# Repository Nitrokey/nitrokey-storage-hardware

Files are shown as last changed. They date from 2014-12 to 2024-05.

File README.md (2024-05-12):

# Nitrokey Storage 2

This repository contains the hardware layout and schematics of the Nitrokey Storage and Nitrokey Storage 2.

## Replacing PCB

You can replace your Nitrokey Storage hardware (PCB) within a few minutes by following these steps:

1. Backup all your data from the Nitrokey. Understand that the RSA keys will be replaced and all data be destroyed!

2. Remove the lid from the USB socket of the Nitrokey.

3. Use a knife to open the casing until you have the PCB removed completely.

4. Remove the smart card and the MicroSD card from the PCB and push them in the new replacement PCB.

5. Place the PCB in the new bottom casing, the one with the CE and FC engravings.

6. Add the other casing (with the Nitrokey label) on top of the bottom casing. Press both casings carefully together until it clicks and the gap is completely closed.

7. Connect the Nitrokey to your computer. Start the Nitrokey App and select “Destroy Encrypted Data” from “Configuration” sub-menu. Note that this will destroy all existing RSA keys and encrypted data.

Your Nitrokey is now ready to use. In case of any problems, please send us an email.

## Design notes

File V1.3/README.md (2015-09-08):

Nitrokey Storage hardware
=========================

Hi hardware freaks,
to use this layout you need the designtool [Designspark PCB](http://www.designspark.com/) (free)

Install the software, the open the projectfile

for the **PROD** version

stick20-p.prj

for the **DEVELOPER** version

Stick20.prj

This work is licensed under the Creative Commons Attribution-ShareAlike 3.0 Unported License. 
To view a copy of this license, visit http://creativecommons.org/licenses/by-sa/3.0/ or send 
a letter to Creative Commons, 444 Castro Street, Suite 900, Mountain View, California, 94041, USA.

Feel free to work with it.

Rudi

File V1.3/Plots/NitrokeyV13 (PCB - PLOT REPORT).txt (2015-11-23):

PLOT REPORT
-----------

Report File:        E:\rudi\Stick\Repositorys\Nitrokey_Hardware\nitrokey-storage-hardware\V1.3\NitrokeyV13 (PCB - PLOT REPORT).txt
Report Written:     Friday, November 20, 2015
Project Path:       E:\rudi\Stick\Repositorys\Nitrokey_Hardware\nitrokey-storage-hardware\V1.3\NitrokeyV13.prj
Design Path:        E:\rudi\Stick\Repositorys\Nitrokey_Hardware\nitrokey-storage-hardware\V1.3\NitrokeyV13.pcb
Design Title:       
Created:            09.09.2011 16:00:27
Last Saved:         20.11.2015 13:58:34
Editing Time:       18637 min
Units:              mm (precision 4)

Device Settings
===============

Gerber Settings
===============

    Leading zero suppression.
    G01 assumed throughout.
    Line termination <*> <CR> <LF>.
    2.5 format absolute inches.

    Format commands defined in Gerber file.
    Aperture table defined in Gerber file.
    Hardware arcs allowed.

Drill Settings
==============

    Excellon Format 1    Format 3.5 absolute in mm.
    No zero suppression.

Plots Output
============

    Plot Job: "E:\rudi\Stick\Repositorys\Nitrokey_Hardware\nitrokey-storage-hardware\V1.3\NitrokeyV13.mop"

Gerber Output
=============

E:\rudi\Stick\Repositorys\Nitrokey_Hardware\nitrokey-storage-hardware\V1.3\Plots\NitrokeyV13 - Top Silkscreen.gbr

    Layers:
    ------------------
    Top Silkscreen
    Board Outlines

    D-Code Shape  (thou)
    -----------------------
    D10    Round 5.00
    D11    Round 4.00
    D12    Round 3.15
    D13    Round 1.97
    D14    Round 8.00
    D15    Round 1.00

Gerber Output
=============

E:\rudi\Stick\Repositorys\Nitrokey_Hardware\nitrokey-storage-hardware\V1.3\Plots\NitrokeyV13 - Top Copper.gbr

    Layers:
    ------------------
    Top Copper
    Board Outlines

    D-Code Shape  (thou)
    ----------------------------------------------
    D10    Round 5.00
    D16    Rectangle 43.31 X 39.37
    D17    Rectangle 51.18 X 59.06
    D18    Rectangle 41.34 X 42.52  Rotation 90
    D19    Rectangle 41.34 X 42.52
    D70    Rectangle 43.31 X 39.37  Rotation 90
    D71    Round 13.78
    D20    Rectangle 48.00 X 88.00
    D21    Rectangle 141.73 X 86.61
    D22    Rectangle 39.37 X 43.31
    D23    Rectangle 39.37 X 43.31  Rotation 90
    D24    Rectangle 86.61 X 47.24
    D25    Round 130.55
    D26    Round 59.18
    D27    Rectangle 59.06 X 74.80
    D28    Rectangle 55.12 X 70.87  Rotation 90
    D29    Round 39.37
    D72    Rectangle 23.62 X 47.24
    D73    Round 17.72
    D74    Round 24.00
    D75    Round 16.00
    D76    Round 12.00
    D77    Round 5.90
    D78    Round 47.24
    D79    Round 37.40

Gerber Output
=============

E:\rudi\Stick\Repositorys\Nitrokey_Hardware\nitrokey-storage-hardware\V1.3\Plots\NitrokeyV13 - Top Copper (Paste).gbr

    Layers:
    ------------------
    Top Copper
    Board Outlines

    D-Code Shape  (thou)
    ----------------------------------------------
    D10    Round 5.00
    D80    Rectangle 39.31 X 35.37
    D81    Rectangle 47.18 X 55.06
    D82    Rectangle 37.34 X 38.52  Rotation 90
    D83    Rectangle 37.34 X 38.52
    D84    Rectangle 39.31 X 35.37  Rotation 90
    D85    Round 9.78
    D86    Rectangle 44.00 X 84.00
    D87    Rectangle 137.73 X 82.61
    D88    Rectangle 35.37 X 39.31
    D89    Rectangle 35.37 X 39.31  Rotation 90
    D90    Rectangle 82.61 X 43.24
    D91    Rectangle 55.06 X 70.80
    D92    Rectangle 51.12 X 66.87  Rotation 90
    D93    Round 35.37
    D94    Rectangle 19.62 X 43.24

Gerber Output
=============

E:\rudi\Stick\Repositorys\Nitrokey_Hardware\nitrokey-storage-hardware\V1.3\Plots\NitrokeyV13 - Documentation.gbr

    Layers:
    ------------------
    Documentation
    Board Outlines

    D-Code Shape  (thou)
    -----------------------
    D10    Round 5.00
    D11    Round 4.00
    D15    Round 1.00
    D95    Round 6.00

Gerber Output
=============

E:\rudi\Stick\Repositorys\Nitrokey_Hardware\nitrokey-storage-hardware\V1.3\Plots\NitrokeyV13 - Top Solder Mask.gbr

    Layers:
    -------------------
    Top Solder Mask
    Board Outlines

    D-Code Shape  (thou)
    ----------------------------------------------
    D10    Round 5.00
    D96    Rectangle 49.31 X 45.37
    D97    Rectangle 57.18 X 65.06
    D98    Rectangle 47.34 X 48.52  Rotation 90
    D99    Rectangle 47.34 X 48.52
    D100   Rectangle 49.31 X 45.37  Rotation 90
    D101   Round 19.78
    D102   Rectangle 54.00 X 94.00
    D103   Rectangle 147.73 X 92.61
    D104   Rectangle 45.37 X 49.31
    D105   Rectangle 45.37 X 49.31  Rotation 90
    D106   Rectangle 92.61 X 53.24
    D107   Round 136.55
    D108   Round 65.18
    D109   Rectangle 65.06 X 80.80
    D110   Rectangle 61.12 X 76.87  Rotation 90
    D111   Round 45.37
    D112   Rectangle 29.62 X 53.24

Gerber Output
=============

E:\rudi\Stick\Repositorys\Nitrokey_Hardware\nitrokey-storage-hardware\V1.3\Plots\NitrokeyV13 - VDD Plane (Powerplane).gbr

    Layers:
    ----------------------------------------------------------------------------------------
    VDD Plane       - Plane Isolation Gap 15.75 Thermal Connect Width 10.00 with 4 Spokes
    Board Outlines

    D-Code Shape  (thou)
    -----------------------------------------
    D113   Round 162.05
    D114   Round 90.68
    D115   Round 17.72  Thermal Relief Pad
    D116   Round 24.00  Thermal Relief Pad
    D117   Round 16.00  Thermal Relief Pad
    D118   Round 55.50
    D119   Round 49.21
    D120   Round 47.50
    D121   Round 70.87
    D122   Round 68.90
    D123   Round 36.50

Gerber Output
=============

E:\rudi\Stick\Repositorys\Nitrokey_Hardware\nitrokey-storage-hardware\V1.3\Plots\NitrokeyV13 - GND Plane (Powerplane).gbr

    Layers:
    ----------------------------------------------------------------------------------------
    GND Plane       - Plane Isolation Gap 15.75 Thermal Connect Width 10.00 with 4 Spokes
    Board Outlines

    D-Code Shape  (thou)
    ------------------------------------------
    D114   Round 90.68
    D115   Round 17.72  Thermal Relief Pad
    D116   Round 24.00  Thermal Relief Pad
    D117   Round 16.00  Thermal Relief Pad
    D118   Round 55.50
    D119   Round 49.21
    D120   Round 47.50
    D121   Round 70.87
    D122   Round 68.90
    D123   Round 36.50
    D124   Round 130.55  Thermal Relief Pad

Gerber Output
=============

E:\rudi\Stick\Repositorys\Nitrokey_Hardware\nitrokey-storage-hardware\V1.3\Plots\NitrokeyV13 - Bottom Copper.gbr

    Layers:
    ------------------
    Bottom Copper
    Board Outlines

    D-Code Shape  (thou)
    ----------------------------------------------
    D10    Round 5.00
    D25    Round 130.55
    D26    Round 59.18
    D29    Round 39.37
    D73    Round 17.72
    D74    Round 24.00
    D75    Round 16.00
    D76    Round 12.00
    D77    Round 5.90
    D79    Round 37.40
    D125   Round 3.94
    D126   Rectangle 39.37 X 66.93  Rotation 90
    D127   Rectangle 33.46 X 62.99
    D128   Rectangle 65.75 X 70.87
    D129   Rectangle 53.15 X 80.71  Rotation 90
    D130   Rectangle 29.53 X 62.99
    D131   Rectangle 72.83 X 74.80  Rotation 90
    D132   Rectangle 25.59 X 84.65
    D133   Rectangle 47.24 X 51.18
    D134   Rectangle 66.93 X 94.49  Rotation 90
    D135   Rectangle 21.26 X 31.50

Gerber Output
=============

E:\rudi\Stick\Repositorys\Nitrokey_Hardware\nitrokey-storage-hardware\V1.3\Plots\NitrokeyV13 - Bottom Copper (Paste).gbr

    Layers:
    ------------------
    Bottom Copper
    Board Outlines

    D-Code Shape  (thou)
    ----------------------------------------------
    D10    Round 5.00
    D93    Round 35.37
    D136   Rectangle 35.37 X 62.93  Rotation 90
    D137   Rectangle 29.46 X 58.99
    D138   Rectangle 61.75 X 66.87
    D139   Rectangle 49.15 X 76.71  Rotation 90
    D140   Rectangle 25.53 X 58.99
    D141   Rectangle 68.83 X 70.80  Rotation 90
    D142   Rectangle 21.59 X 80.65
    D143   Rectangle 43.24 X 47.18
    D144   Rectangle 62.93 X 90.49  Rotation 90
    D145   Rectangle 17.26 X 27.50

Gerber Output
=============

E:\rudi\Stick\Repositorys\Nitrokey_Hardware\nitrokey-storage-hardware\V1.3\Plots\NitrokeyV13 - Bottom Silkscreen.gbr

    Layers:
    ---------------------
    Bottom Silkscreen

    D-Code Shape  (thou)
    -----------------------
    D10    Round 5.00
    D13    Round 1.97
    D14    Round 8.00

Gerber Output
=============

E:\rudi\Stick\Repositorys\Nitrokey_Hardware\nitrokey-storage-hardware\V1.3\Plots\NitrokeyV13 - Bottom Solder Mask.gbr

    Layers:
    ----------------------
    Bottom Solder Mask
    Board Outlines

    D-Code Shape  (thou)
    -----------------------------------------------
    D10    Round 5.00
    D107   Round 136.55
    D108   Round 65.18
    D111   Round 45.37
    D146   Rectangle 45.37 X 72.93  Rotation 90
    D147   Rectangle 39.46 X 68.99
    D148   Rectangle 71.75 X 76.87
    D149   Rectangle 59.15 X 86.71  Rotation 90
    D150   Rectangle 35.53 X 68.99
    D151   Rectangle 78.83 X 80.80  Rotation 90
    D152   Rectangle 31.59 X 90.65
    D153   Rectangle 53.24 X 57.18
    D154   Rectangle 72.93 X 100.49  Rotation 90
    D155   Rectangle 27.26 X 37.50

NC Drill Output
===============

E:\rudi\Stick\Repositorys\Nitrokey_Hardware\nitrokey-storage-hardware\V1.3\Plots\NitrokeyV13 - Drill Data - [Through Hole].drl

    Output:
    ---------------------------
    Plated Round Drill Holes
    Plated Slots
    Plated Board Outlines

    Tool  Size         Count   ID
    ------------------------------------
    T001  000.00787 in 27    I
    T002  000.00800 in 12    D
    T003  000.01200 in 51    E
    T004  000.04724 in 2     K
    T005  000.09843 in 2     J
    ------------------------------------
    Total              94
    ------------------------------------

E:\rudi\Stick\Repositorys\Nitrokey_Hardware\nitrokey-storage-hardware\V1.3\Plots\NitrokeyV13 - Drill Data - [Through Hole] (Unplated).drl

    Output:
    -----------------------------
    Unplated Round Drill Holes
    Unplated Slots
    Unplated Board Outlines

    Tool  Size         Count   ID
    ------------------------------------
    T001  000.02500 in 1
    T002  000.03543 in 3     S
    ------------------------------------
    Total              4
    ------------------------------------

Gerber Output
=============

E:\rudi\Stick\Repositorys\Nitrokey_Hardware\nitrokey-storage-hardware\V1.3\Plots\NitrokeyV13 - Drill Ident Drawing - [Through Hole].gbr

    Layers:
    ------------------
    [Through Hole]
    Board Outlines

Drill Ident Drawing
===================

    Drill Plated Size Shape ID
    -----------------------------------
    8     Y      100  Round D
    12    Y      100  Round E
    8     Y      100  Round I
    98    Y      100  Round J
    47    Y      100  Round K
    35           100  Round S

    D-Code Shape  (thou)
    -----------------------
    D10    Round 5.00
    D150   Round 100.00

Gerber Output
=============

E:\rudi\Stick\Repositorys\Nitrokey_Hardware\nitrokey-storage-hardware\V1.3\Plots\NitrokeyV13 - Board.gbr

    Layers:
    ------------------
    Board Outlines

    D-Code Shape  (thou)
    -----------------------
    D10    Round 5.00

End Of Report.

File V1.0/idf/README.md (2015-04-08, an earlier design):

Creating IDF libraries
======================

Two files are needed to create an IDF library. An .emn and an .emp. 

* .emn: Holds information about the PCB board, the drilled holes and the placement of the parts.
* .emp: Holds information about each class of a component that is used at .emn placement.

To create a 3D model of the IDF library, you can open the .emn file using FreeCAD. 
Then you can save the 3D models as a .FCStd file.

The procedure of creating and manipulating an IDF library is explained below (per project).

Creating the .emp
-----------------
	The .emp file consists of a header section at the beginning. This sections is followed by electrical sections. 
	Each electrical section has the outline info as a series of points in a 2D plane, and a height value. 
	The outline must be a closed curve, thus you need to place twice the point that you started, 
	once at the beginning and once at the end of the section (returning to starting point).
	If it is a rectangular outline, use point (0,0) as the center of it.

Creating the .emn
-----------------
	The .emn file consists of a header section, a board section, a drilled_holes section and a placement section. 
	The board section describes the boad outline and height. 
	The placement section is a series of placement declarations, 
	each one declaring the type of the component (from .emp file), a placeholder name, 
	the positioning at the 3D plane, a rotation factor and the side of the board that is to be placed (top/bottom)

Nitrokey Pro
------------
	For Nitrokey Pro, you have to open the .kicad_pcb file. 
	There is a section that lists all the modules. 
	Each module has the component type (BOM file), the placeholder name (emp placement),
	the positioning and rotation (emp placement). 

You have to manually create/edit the .emp file consulting the BOM and manuals.
You have to manually create/edit the .emn file consulting the .kicad_pcb file for the placement coordinates.

*Note 1: Depending on the orientation of each component at it's electrical section, 
         you may need to use rotation to match the real design.*

*Note 2: Depending on the side that the component is placed, you may have to calculate some offsets because 
         the coords seems to be mirrored on the other side (and you have to mirror them again so that it aligns).*

Nitrokey Storage
----------------
	For Nitrokey Storage, you have to use DesignSpark. 
	First you export the pcb design as a set of .idl and .idf files [3](without the height adjusting, see next par.).
	Rename .idl to .emp and .idf to .emn (they are essentially the same format).
	You will have to manually edit the .emp file to include all the electrical sections 
	(consulting the BOM, manualls and naming of the components from the .emn file). 
	The .emn file doen't need any changes.

Notes (on Storage):
1) Right now the height of the short capacitors and resistors is not accurate. 
   An approximation is used instead (worst case found from the family of each component).
2) For some components the length does not include the extra soldering area.
3) Electrical sections for the R0603, C0603, C0603K and C1206 need to be rewritten with (0,0) as their center. 
   Also their orientation at the placement section need to be changed appropriatelly. 

For both devices
----------------
	Create a second module to model USB.

Useful Links
------------
[1] https://www.simplifiedsolutionsinc.com/images/idf_v30_spec.pdf
[2] https://sourceforge.net/projects/kicad-3d/
[3] http://www.rs-online.com/designspark/electronics/eng/tutorial/exporting-designs-from-designspark-pcb-to-mechanical-cad

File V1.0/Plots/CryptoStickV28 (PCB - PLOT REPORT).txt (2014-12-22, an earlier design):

PLOT REPORT
-----------

Report File    : E:\rudi\Stick\Repositorys\assembla\tags\v2.0-production-rc8\CryptoStickV28 (PCB - PLOT REPORT).txt
Report Written : Thursday, November 20, 2014
Project Path   : E:\rudi\Stick\Repositorys\assembla\tags\v2.0-production-rc8\stick28-p.prj
Design Path    : E:\rudi\Stick\Repositorys\assembla\tags\v2.0-production-rc8\CryptoStickV28.pcb
Design Title   : 
Created        : 09.09.2011 16:00:27
Last Saved     : 20.11.2014 11:46:05
Editing Time   : 13445 min
Units          : mm (precision 4)

Device Settings
===============

Gerber Settings
===============

    Leading zero suppression.
    G01 assumed throughout.
    Line termination <*> <CR> <LF>.
    2.3 format absolute inches.

    Format commands defined in Gerber file.
    Aperture table defined in Gerber file.
    Hardware arcs allowed.

Drill Settings
==============

    Excellon Format 1    Format 2.3 absolute in mm.
    No zero suppression.

Plots Output
============

    Plot Job: "E:\rudi\Stick\Repositorys\assembla\tags\v2.0-production-rc7\CryptoStickV27.mop"

Gerber Output
=============

E:\rudi\Stick\Repositorys\assembla\tags\v2.0-production-rc8\Plots\CryptoStickV28 - Top Silkscreen.gbr

    Layers:
    ----------------
    Top Silkscreen
    Board Outlines

    D-Code  Shape  (thou)
    ---------------------
    D78     Round 5.00
    D90     Round 1.97
    D91     Round 8.00
    D107    Round 4.00
    D108    Round 3.15
    D109    Round 1.00

Gerber Output
=============

E:\rudi\Stick\Repositorys\assembla\tags\v2.0-production-rc8\Plots\CryptoStickV28 - Top Copper.gbr

    Layers:
    ----------------
    Top Copper
    Board Outlines

    D-Code  Shape  (thou)
    --------------------------------------------
    D19     Round 130.55
    D70     Round 59.18
    D71     Round 39.37
    D72     Round 39.37
    D73     Round 17.72
    D74     Round 24.00
    D75     Round 16.00
    D76     Round 12.00
    D77     Round 5.90
    D78     Round 5.00
    D110    Rectangle 62.99 X 70.87
    D111    Rectangle 41.34 X 42.52  Rotation 90
    D112    Rectangle 41.34 X 42.52
    D113    Rectangle 43.31 X 39.37
    D114    Rectangle 43.31 X 39.37  Rotation 90
    D115    Round 13.78
    D116    Rectangle 48.00 X 88.00
    D117    Rectangle 141.73 X 86.61
    D118    Rectangle 39.37 X 43.31
    D119    Rectangle 39.37 X 43.31  Rotation 90
    D120    Rectangle 86.61 X 47.24
    D121    Rectangle 59.06 X 74.80
    D122    Rectangle 55.12 X 70.87  Rotation 90
    D123    Rectangle 23.62 X 47.24
    D124    Round 47.24

Gerber Output
=============

E:\rudi\Stick\Repositorys\assembla\tags\v2.0-production-rc8\Plots\CryptoStickV28 - Top Copper (Paste).gbr

    Layers:
    ------------
    Top Copper

    D-Code  Shape  (thou)
    --------------------------------------------
    D79     Round 35.37
    D125    Rectangle 58.99 X 66.87
    D126    Rectangle 37.34 X 38.52  Rotation 90
    D127    Rectangle 37.34 X 38.52
    D128    Rectangle 39.31 X 35.37
    D129    Rectangle 39.31 X 35.37  Rotation 90
    D130    Round 9.78
    D131    Rectangle 44.00 X 84.00
    D132    Rectangle 137.73 X 82.61
    D133    Rectangle 35.37 X 39.31
    D134    Rectangle 35.37 X 39.31  Rotation 90
    D135    Rectangle 82.61 X 43.24
    D136    Rectangle 55.06 X 70.80
    D137    Rectangle 51.12 X 66.87  Rotation 90
    D138    Rectangle 19.62 X 43.24

Gerber Output
=============

E:\rudi\Stick\Repositorys\assembla\tags\v2.0-production-rc8\Plots\CryptoStickV28 - Documentation.gbr

    Layers:
    ----------------
    Documentation
    Board Outlines

    D-Code  Shape  (thou)
    ---------------------
    D78     Round 5.00
    D107    Round 4.00
    D109    Round 1.00
    D139    Round 6.00

Gerber Output
=============

E:\rudi\Stick\Repositorys\assembla\tags\v2.0-production-rc8\Plots\CryptoStickV28 - Top Solder Mask.gbr

    Layers:
    -----------------
    Top Solder Mask

    D-Code  Shape  (thou)
    --------------------------------------------
    D92     Round 136.55
    D93     Round 65.18
    D94     Round 45.37
    D105    Round 45.37
    D140    Rectangle 68.99 X 76.87
    D141    Rectangle 47.34 X 48.52  Rotation 90
    D146    Rectangle 47.34 X 48.52
    D147    Rectangle 49.31 X 45.37
    D148    Rectangle 49.31 X 45.37  Rotation 90
    D149    Round 19.78
    D150    Rectangle 54.00 X 94.00
    D151    Rectangle 147.73 X 92.61
    D152    Rectangle 45.37 X 49.31
    D153    Rectangle 45.37 X 49.31  Rotation 90
    D154    Rectangle 92.61 X 53.24
    D155    Rectangle 65.06 X 80.80
    D156    Rectangle 61.12 X 76.87  Rotation 90
    D157    Rectangle 29.62 X 53.24

Gerber Output
=============

E:\rudi\Stick\Repositorys\assembla\tags\v2.0-production-rc8\Plots\CryptoStickV28 - VDD Plane (Powerplane).gbr

    Layers:
    --------------------------------------------------------------------------------------
    VDD Plane        - Plane Isolation Gap 15.75 Thermal Connect Width 10.00 with 4 Spokes
    Board Outlines

    D-Code  Shape  (thou)
    ---------------------------------------
    D11     Round 49.21
    D12     Round 55.50
    D13     Round 47.50
    D14     Round 24.00  Thermal Relief Pad
    D15     Round 17.72  Thermal Relief Pad
    D16     Round 16.00  Thermal Relief Pad
    D17     Round 36.50
    D142    Round 162.05
    D143    Round 90.68
    D144    Round 70.87
    D145    Round 39.37  Thermal Relief Pad

Gerber Output
=============

E:\rudi\Stick\Repositorys\assembla\tags\v2.0-production-rc8\Plots\CryptoStickV28 - GND Plane (Powerplane).gbr

    Layers:
    --------------------------------------------------------------------------------------
    GND Plane        - Plane Isolation Gap 15.75 Thermal Connect Width 10.00 with 4 Spokes
    Board Outlines

    D-Code  Shape  (thou)
    ----------------------------------------
    D10     Round 130.55  Thermal Relief Pad
    D11     Round 90.68
    D12     Round 70.87
    D13     Round 39.37  Thermal Relief Pad
    D14     Round 49.21
    D15     Round 55.50
    D16     Round 47.50
    D17     Round 24.00  Thermal Relief Pad
    D18     Round 17.72  Thermal Relief Pad
    D19     Round 16.00  Thermal Relief Pad
    D70     Round 36.50

Gerber Output
=============

E:\rudi\Stick\Repositorys\assembla\tags\v2.0-production-rc8\Plots\CryptoStickV28 - Bottom Copper.gbr

    Layers:
    ----------------
    Bottom Copper
    Board Outlines

    D-Code  Shape  (thou)
    --------------------------------------------
    D71     Round 3.94
    D20     Round 130.55
    D21     Round 59.18
    D22     Round 39.37
    D23     Rectangle 39.37 X 66.93  Rotation 90
    D24     Rectangle 33.46 X 62.99
    D25     Rectangle 65.75 X 70.87
    D26     Rectangle 53.15 X 80.71  Rotation 90
    D27     Rectangle 29.53 X 62.99
    D28     Rectangle 72.83 X 74.80  Rotation 90
    D29     Rectangle 25.59 X 84.65
    D72     Rectangle 47.24 X 51.18
    D73     Rectangle 66.93 X 94.49  Rotation 90
    D74     Rectangle 21.26 X 31.50
    D75     Round 39.37
    D76     Round 17.72
    D77     Round 24.00
    D78     Round 16.00
    D79     Round 12.00
    D80     Round 5.90
    D81     Round 5.00

Gerber Output
=============

E:\rudi\Stick\Repositorys\assembla\tags\v2.0-production-rc8\Plots\CryptoStickV28 - Bottom Copper (Paste).gbr

    Layers:
    ----------------
    Bottom Copper
    Board Outlines

    D-Code  Shape  (thou)
    --------------------------------------------
    D81     Round 5.00
    D82     Round 35.37
    D83     Rectangle 35.37 X 62.93  Rotation 90
    D84     Rectangle 29.46 X 58.99
    D85     Rectangle 61.75 X 66.87
    D86     Rectangle 49.15 X 76.71  Rotation 90
    D87     Rectangle 25.53 X 58.99
    D88     Rectangle 68.83 X 70.80  Rotation 90
    D89     Rectangle 21.59 X 80.65
    D90     Rectangle 43.24 X 47.18
    D91     Rectangle 62.93 X 90.49  Rotation 90
    D92     Rectangle 17.26 X 27.50

Gerber Output
=============

E:\rudi\Stick\Repositorys\assembla\tags\v2.0-production-rc8\Plots\CryptoStickV28 - Bottom Silkscreen.gbr

    Layers:
    -------------------
    Bottom Silkscreen
    Board Outlines

    D-Code  Shape  (thou)
    ---------------------
    D81     Round 5.00
    D93     Round 1.97
    D94     Round 8.00

Gerber Output
=============

E:\rudi\Stick\Repositorys\assembla\tags\v2.0-production-rc8\Plots\CryptoStickV28 - Bottom Solder Mask.gbr

    Layers:
    --------------------
    Bottom Solder Mask
    Board Outlines

    D-Code  Shape  (thou)
    ---------------------------------------------
    D81     Round 5.00
    D95     Round 136.55
    D96     Round 65.18
    D97     Round 45.37
    D98     Rectangle 45.37 X 72.93  Rotation 90
    D99     Rectangle 39.46 X 68.99
    D100    Rectangle 71.75 X 76.87
    D101    Rectangle 59.15 X 86.71  Rotation 90
    D102    Rectangle 35.53 X 68.99
    D103    Rectangle 78.83 X 80.80  Rotation 90
    D104    Rectangle 31.59 X 90.65
    D105    Rectangle 53.24 X 57.18
    D106    Rectangle 72.93 X 100.49  Rotation 90
    D107    Rectangle 27.26 X 37.50
    D108    Round 45.37

NC Drill Output
===============

E:\rudi\Stick\Repositorys\assembla\tags\v2.0-production-rc8\Plots\CryptoStickV28 - Drill Data - Through Hole.drl

    Output:
    --------------------------
    Plated Round Drill Holes
    Plated Slots
    Plated Board Outlines

    Tool   Size       Count    ID
    -----------------------------
    T001   00.008 in  27     I
    T002   00.008 in  12     D
    T003   00.012 in  51     E
    T004   00.028 in  7      L
    T005   00.047 in  2      K
    T006   00.098 in  2      J
    -----------------------------
    Total             101
    -----------------------------
    Tool   Size       Count    ID
    -----------------------------
    T001   00.025 in  1
    -----------------------------
    Total             1
    -----------------------------

Gerber Output
=============

E:\rudi\Stick\Repositorys\assembla\tags\v2.0-production-rc8\Plots\CryptoStickV28 - Drill Ident Drawing - Through Hole.gbr

    Layers:
    ----------------
    [Through Hole]

Drill Ident Drawing
===================

    Drill  Plated  Size  Shape  ID
    ------------------------------
    8      Y       100   Round  D
    12     Y       100   Round  E
    8      Y       100   Round  I
    98     Y       100   Round  J
    47     Y       100   Round  K
    28     Y       100   Round  L

    D-Code  Shape  (thou)
    ---------------------
    D81     Round 5.00
    D109    Round 100.00

Gerber Output
=============

E:\rudi\Stick\Repositorys\assembla\tags\v2.0-production-rc8\Plots\CryptoStickV28 - Kontur.gbr

    Layers:
    ----------------
    Board Outlines

    D-Code  Shape  (thou)
    ---------------------
    D81     Round 5.00

End Of Report.

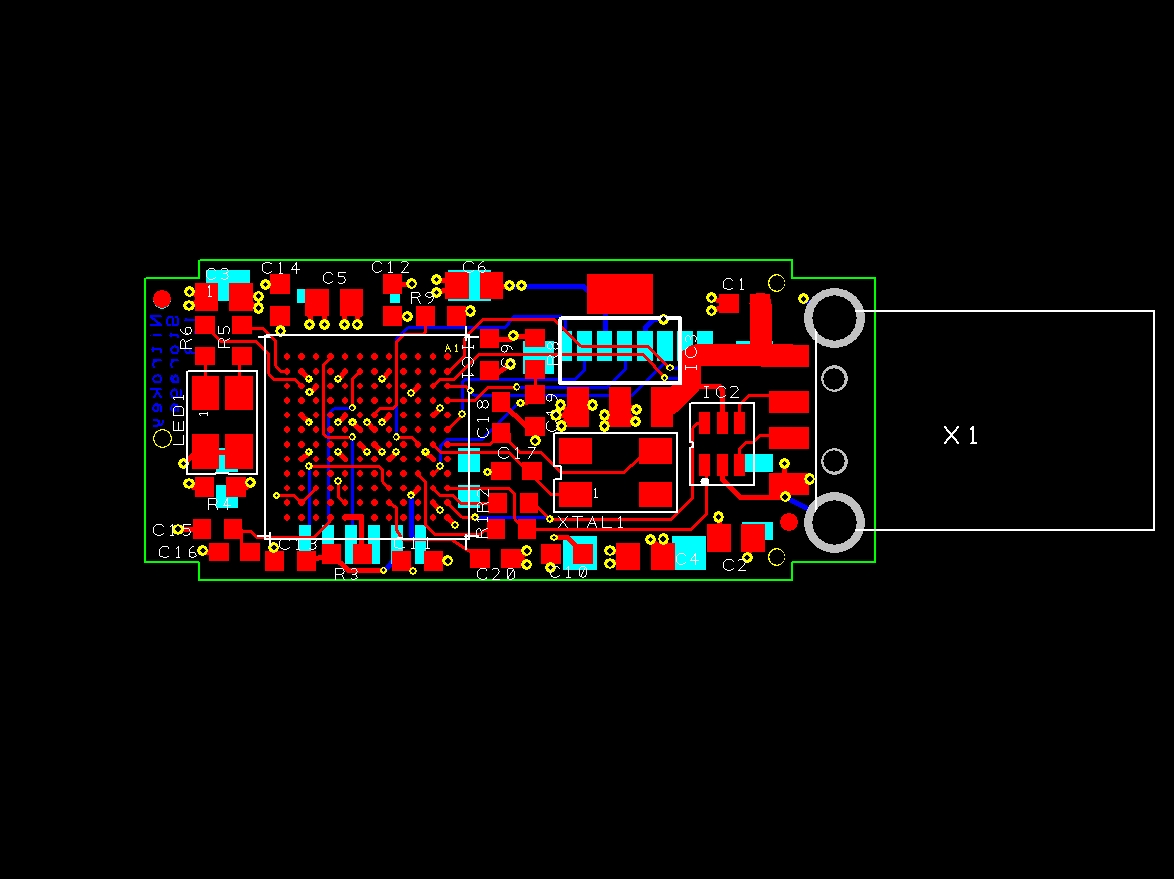
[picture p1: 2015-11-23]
V1.3/Plots/NitrokeyV13.jpg

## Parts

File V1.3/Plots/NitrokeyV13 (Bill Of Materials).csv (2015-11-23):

"Report File:,""E:\rudi\Stick\Repositorys\Nitrokey_Hardware\nitrokey-storage-hardware\V1.3\NitrokeyV13 (Bill Of Materials).csv"""
"Report Written:,""Friday, November 20, 2015"""
"Project Path:,""E:\rudi\Stick\Repositorys\Nitrokey_Hardware\nitrokey-storage-hardware\V1.3\NitrokeyV13.prj"""
"Design Path:,""E:\rudi\Stick\Repositorys\Nitrokey_Hardware\nitrokey-storage-hardware\V1.3\NitrokeyV13.pcb"""
"Design Title:,"""""
"Created:,""09.09.2011 16:00:27"""
"Last Saved:,""20.11.2015 13:58:34"""
"Editing Time:,""18638 min"""
"Units:,""mm (precision 4)"""
Bill of Materials generated with DesignSpark PCB - www.DesignSpark.com/pcb
--------------------------------------------------------------------------
"Ref Name,""Qty"",""Component"",""Value"",""Package"",""Manufacturer"",""MPN"",""RS Part Number"",""Other Part Number"",""Description"""
"ScCon,""1"",""++CONNECTOR_SC"",""Molex 78646-3001"",""USER"","""","""","""","""","""""
"CONN1,""1"",""++CONNECTOR_SD"",""Molex 104031-0811"",""USER"","""","""","""","""","""""
"X1,""1"",""++CONNECTOR_USB-BUCHSE-A_NEU"",""Keystone Electronics 931"",""++CONNECTOR_USB-BUCHSE-A"","""","""","""","""","""""
"LED1,""1"",""598-8621-207F"",""Dialight 598-8621-207F"",""USER"","""","""","""","""","""""
"XTAL1,""1"",""ABMM2-12.000MHZ-E2-T"",""ABMM2-12.000MHZ-E2-T"",""USER"","""","""","""","""",""ABMM2-16.000MHZ-E2-T"""
"IC1,""1"",""AT32UC3A3256S"",""AT32UC3A3256S-CTUR"",""BGA144-08"","""","""","""","""","""""
"C1,""1"",""C-EUC0603"",""4u7"",""C0603"","""","""","""","""",""CAPACITOR, European symbol"""
"C16,""1"",""C-EUC0603"",""4u7"",""C0603"","""","""","""","""",""CAPACITOR, European symbol"""
"C20,""1"",""C-EUC0603"",""4u7"",""C0603"","""","""","""","""",""CAPACITOR, European symbol"""
"C17,""1"",""C-EUC0603"",""15p"",""C0603"","""","""","""","""",""CAPACITOR, European symbol"""
"C18,""1"",""C-EUC0603"",""15p"",""C0603"","""","""","""","""",""CAPACITOR, European symbol"""
"C19,""1"",""C-EUC0603K"",""10p"",""C0603K"","""","""","""","""",""CAPACITOR, European symbol"""
"C9,""1"",""C-EUC0603K"",""100n"",""C0603K"","""","""","""","""",""CAPACITOR, European symbol"""
"C13,""1"",""C-EUC0603K"",""100n"",""C0603K"","""","""","""","""",""CAPACITOR, European symbol"""
"C10,""1"",""C-EUC0603K"",""100n"",""C0603K"","""","""","""","""",""CAPACITOR, European symbol"""
"C11,""1"",""C-EUC0603K"",""100n"",""C0603K"","""","""","""","""",""CAPACITOR, European symbol"""
"C12,""1"",""C-EUC0603K"",""100n"",""C0603K"","""","""","""","""",""CAPACITOR, European symbol"""
"C14,""1"",""C-EUC0603K"",""100n"",""C0603K"","""","""","""","""",""CAPACITOR, European symbol"""
"C15,""1"",""C-EUC0603K"",""100n"",""C0603K"","""","""","""","""",""CAPACITOR, European symbol"""
"C2,""1"",""C-EUC0805"",""47uf"",""C1206"","""","""","""","""",""CAPACITOR, European symbol"""
"C3,""1"",""C-EUC0805"",""47uf"",""C1206"","""","""","""","""",""CAPACITOR, European symbol"""
"C4,""1"",""C-EUC0805"",""47uf"",""C1206"","""","""","""","""",""CAPACITOR, European symbol"""
"C5,""1"",""C-EUC0805"",""47uf"",""C1206"","""","""","""","""",""CAPACITOR, European symbol"""
"C6,""1"",""C-EUC0805"",""47uf"",""C1206"","""","""","""","""",""CAPACITOR, European symbol"""
"J8,""1"",""Passermarke"","""",""USER"","""","""","""","""","""""
"J9,""1"",""Passermarke"","""",""USER"","""","""","""","""","""""
"J10,""1"",""Passermarke"","""",""USER"","""","""","""","""","""""
"J11,""1"",""Passermarke"","""",""USER"","""","""","""","""","""""
"R9,""1"",""R-EU_R0603"",""2k2"",""R0603"","""","""","""","""",""RESISTOR, European symbol"""
"R8,""1"",""R-EU_R0603"",""6k8"",""R0603"","""","""","""","""",""RESISTOR, European symbol"""
"R3,""1"",""R-EU_R0603"",""10"",""R0603"","""","""","""","""",""RESISTOR, European symbol"""
"R1,""1"",""R-EU_R0603"",""22"",""R0603"","""","""","""","""",""RESISTOR, European symbol"""
"R2,""1"",""R-EU_R0603"",""22"",""R0603"","""","""","""","""",""RESISTOR, European symbol"""
"R5,""1"",""R-EU_R0603"",""220"",""R0603"","""","""","""","""",""RESISTOR, European symbol"""
"R6,""1"",""R-EU_R0603"",""220"",""R0603"","""","""","""","""",""RESISTOR, European symbol"""
"R4,""1"",""R-EU_R0603"",""220k"",""R0603"","""","""","""","""",""RESISTOR, European symbol"""
"IC3,""1"",""TLV1117-33CDCY"",""TLV1117-33CDCY"",""---MJ_SOT223"","""","""","""","""","""""
"IC2,""1"",""TPD2S017"",""TPD2S017DBVR"",""USER"","""",""TPD2S017DBVR"","""","""","""""

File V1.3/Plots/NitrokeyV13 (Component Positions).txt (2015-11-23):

Component Positions Report
--------------------------

Report File:    E:\rudi\Stick\Repositorys\Nitrokey_Hardware\nitrokey-storage-hardware\V1.3\NitrokeyV13 (Component Positions).txt
Report Written: Friday, November 20, 2015
Project Path:   E:\rudi\Stick\Repositorys\Nitrokey_Hardware\nitrokey-storage-hardware\V1.3\NitrokeyV13.prj
Design Path:    E:\rudi\Stick\Repositorys\Nitrokey_Hardware\nitrokey-storage-hardware\V1.3\NitrokeyV13.pcb
Design Title:
Created:        09.09.2011 16:00:27
Last Saved:     20.11.2015 13:58:34
Editing Time:   18638 min
Units:          mm (precision 4)

Name      Component                     Side                    Centre X    Centre Y  Rotation
----------------------------------------------------------------------------------------------
ScCon     ++CONNECTOR_SC                Bottom                   11.1876      9.2085    270.00
CONN1     ++CONNECTOR_SD                Bottom                   27.5916      8.7271    180.00
X1        ++CONNECTOR_USB-BUCHSE-A_NEU  Top                      44.7752      8.7605      0.00
LED1      598-8621-207F                 Top                       4.2356      8.6355     90.00
XTAL1     ABMM2-12.000MHZ-E2-T          Top                      25.7935      5.8855      0.00
IC1       AT32UC3A3256S                 Top                      12.1935      7.8355    270.00
C1        C-EUC0603                     Top                      32.8500     15.1500      0.00
C16       C-EUC0603                     Top                       4.9275      1.5325    180.00
C17       C-EUC0603                     Top                      20.3935      5.9855    180.00
C18       C-EUC0603                     Top                      19.5435      8.8855     90.00
C20       C-EUC0603                     Top                      19.2435      1.1855      0.00
C9        C-EUC0603K                    Top                      18.8935     12.3355    270.00
C10       C-EUC0603K                    Top                      23.1435      1.4355      0.00
C11       C-EUC0603K                    Top                      14.9435      1.0355      0.00
C12       C-EUC0603K                    Top                      13.5935     15.3355    270.00
C13       C-EUC0603K                    Top                       7.9935      1.0355      0.00
C14       C-EUC0603K                    Top                       7.4435     15.3355     90.00
C15       C-EUC0603K                    Top                       4.1435      5.0855      0.00
C19       C-EUC0603K                    Top                      21.3935      9.2855     90.00
C2        C-EUC0805                     Top                      32.4000      2.3000      0.00
C3        C-EUC0805                     Top                       4.3500     15.5000      0.00
C4        C-EUC0805                     Top                      27.4500      1.3000      0.00
C5        C-EUC0805                     Top                      10.3935     15.1855    180.00
C6        C-EUC0805                     Top                      18.0500     16.1355    180.00
J8        Passermarke                   Bottom                    0.9435     15.3700      0.00
J9        Passermarke                   Top                       0.9435     15.4000      0.00
J10       Passermarke                   Top                      35.3200      3.2000      0.00
J11       Passermarke                   Bottom                   35.3100      3.2000      0.00
R1        R-EU_R0603                    Top                      20.0935      2.7855      0.00
R2        R-EU_R0603                    Top                      20.1935      4.2355      0.00
R3        R-EU_R0603                    Top                      11.0935      1.4355    180.00
R4        R-EU_R0603                    Top                       3.9935      2.7855      0.00
R5        R-EU_R0603                    Top                       5.3435     13.1355     90.00
R6        R-EU_R0603                    Top                       3.2935     13.1355     90.00
R8        R-EU_R0603                    Top                      21.3935     12.3855     90.00
R9        R-EU_R0603                    Top                      16.2435     14.4855    180.00
IC3       TLV1117-33CDCY                Top                      26.0435     12.5768      0.00
IC2       TPD2S017                      Top                      31.6435      7.4355      0.00
----------------------------------------------------------------------------------------------

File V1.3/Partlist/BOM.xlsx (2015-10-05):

Nitrokey 1.2
Quantity
1 | AT32UC3A3256S-CTUT | Digikey | AT32UC3A3256S-CTUT | http://de.mouser.com/Search/ProductDetail.aspx
1 | TLV1117-33CDCY | Digikey | 296-26776-5-ND | http://www.digikey.de/product-detail/de/TLV1117-33CDCY/296-26776-5-ND/1677125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
1 | Dialight 598-8621-207F | Digikey | 350-2082-1-ND | http://www.digikey.de/product-detail/de/598-8621-207F/350-2082-1-ND/1291386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
1 | Molex - 0480372200 | Digikey | WM3983TR-ND | http://www.digikey.com/product-detail/en/0480372200/WM3983CT-ND/2421836
1 | ABMM2-12.000MHZ-E2-T | Digikey | 535-9631-1-ND | http://www.digikey.de/product-detail/de/ABMM2-12.000MHZ-E2-T/535-9631-1-ND/1237098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
2 | R 10 Ohm , 0603 | Digikey | P22GCT-ND | http://www.digikey.de/product-detail/de/ERJ-3GEYJ220V/P22GCT-ND/134662
1 | R 22 Ohm , 0603 | Digikey | P10GCT-ND | http://www.digikey.de/product-detail/de/ERJ-3GEYJ100V/P10GCT-ND/62816
1 | R 220K Ohm , 0603 | Digikey | P220KGCT-ND | http://www.digikey.de/product-detail/de/ERJ-3GEYJ224V/P220KGCT-ND/135084
2 | R 220 Ohm , 0603 | Digikey | P220GCT-ND | http://www.digikey.de/product-detail/de/ERJ-3GEYJ221V/P220GCT-ND/134754
1 | R 6.8k Ohm , 0603 | Digikey | P6.80KHCT-ND | http://www.digikey.de/product-detail/de/ERJ-3EKF6801V/P6.80KHCT-ND/1746802
1 | R 2.2k Ohm , 0603 | Digikey | P2.2KGCT-ND | http://www.digikey.de/product-detail/de/ERJ-3GEYJ222V/P2.2KGCT-ND/135077
3 | C 4u7, 0603 | Digikey | 1276-2087-1-ND | http://www.digikey.de/product-detail/de/CL10B475KQ8NQNC/1276-2087-1-ND/3890173
5 | C 47u, 0805 | Digikey | 1276-2420-1-ND | http://www.digikey.de/product-detail/de/CL21A476MQCLRNC/1276-2420-1-ND/3890506
7 | C 100n, 0603 | Digikey | 445-6938-1-ND | http://www.digikey.de/product-detail/de/CGA3E3X7S2A104K/445-6938-1-ND/2672956
2 | C 15p, 0603 | Digikey | 399-7853-1-ND | http://www.digikey.de/product-detail/de/C0603C150J1GACTU/399-7853-1-ND/3471576
1 | C 10p, 0603 | Digikey | 445-4651-1-ND | http://www.digikey.de/product-detail/de/C0603C0G1E100D/445-4651-1-ND/2050257
1 | TPD2S017 | Mouser | TPD2S017DBVR | http://de.mouser.com/ProductDetail/Texas-Instruments/TPD2S017DBVR/
1 | Gehäuse | Mouser | P3A-201005S | http://de.mouser.com/Search/ProductDetail.aspx
1 | Micro Sim - 78646-3001 | Molex | 78646-3001 | http://de.mouser.com/ProductDetail/Molex/78646-3001/
1 | Micro SD - 104031-0811 | Molex | 104031-0811 | http://de.mouser.com/ProductDetail/Molex/104031-0811/
Gelb = Nicht bestücken
Geändert gegenüber Nitrokey 1.1

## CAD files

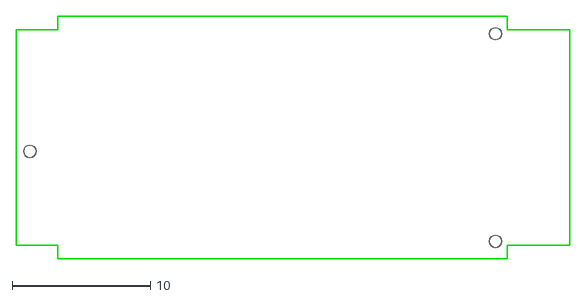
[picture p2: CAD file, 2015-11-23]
V1.3/Plots/NitrokeyV13.dxf
40.0 x 17.6

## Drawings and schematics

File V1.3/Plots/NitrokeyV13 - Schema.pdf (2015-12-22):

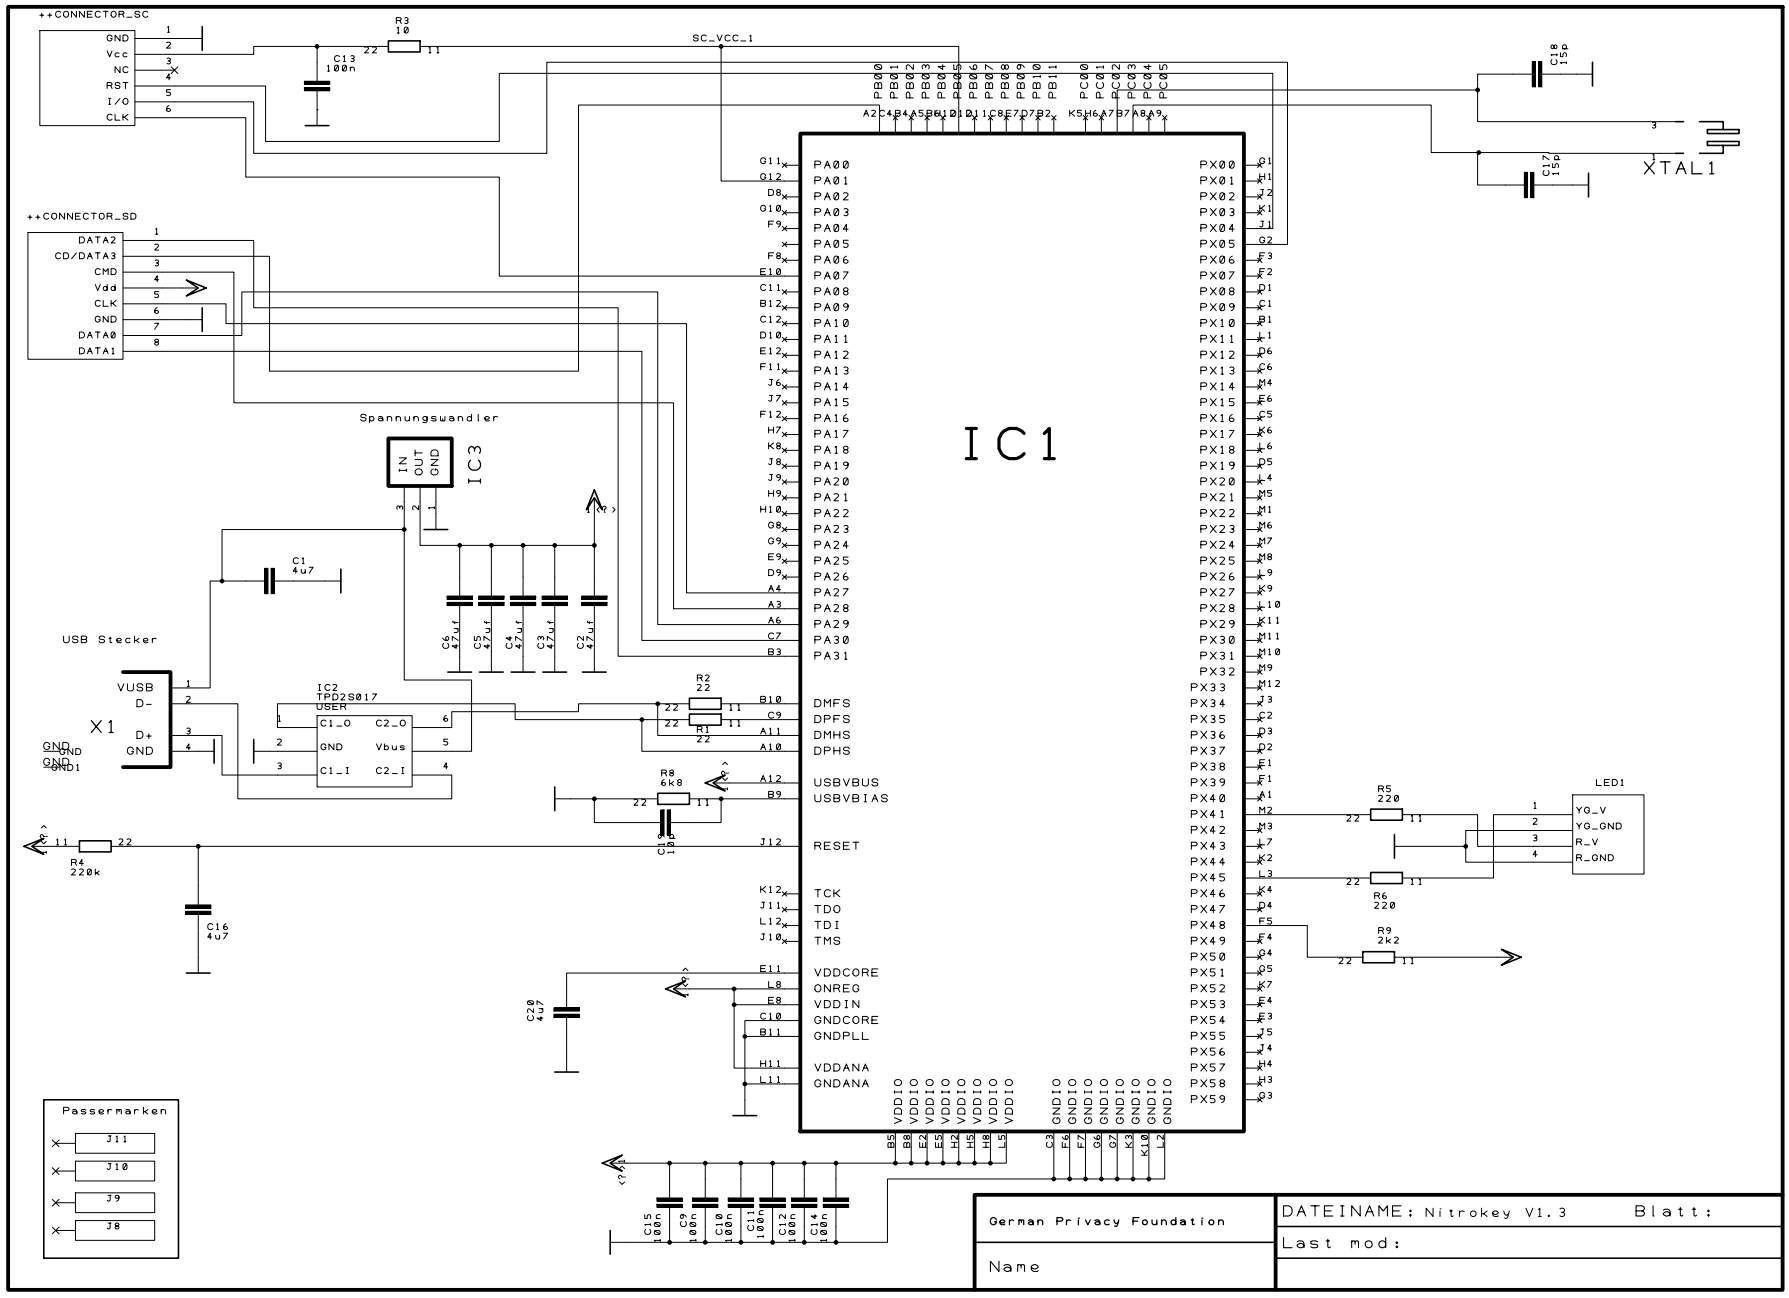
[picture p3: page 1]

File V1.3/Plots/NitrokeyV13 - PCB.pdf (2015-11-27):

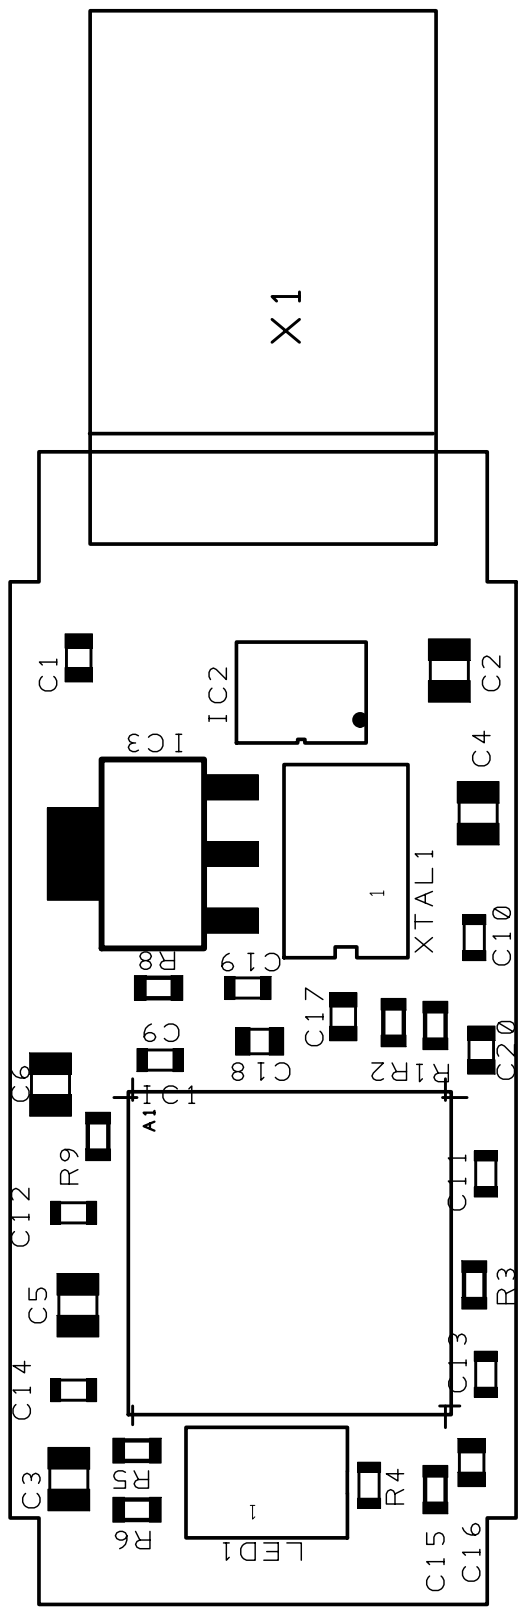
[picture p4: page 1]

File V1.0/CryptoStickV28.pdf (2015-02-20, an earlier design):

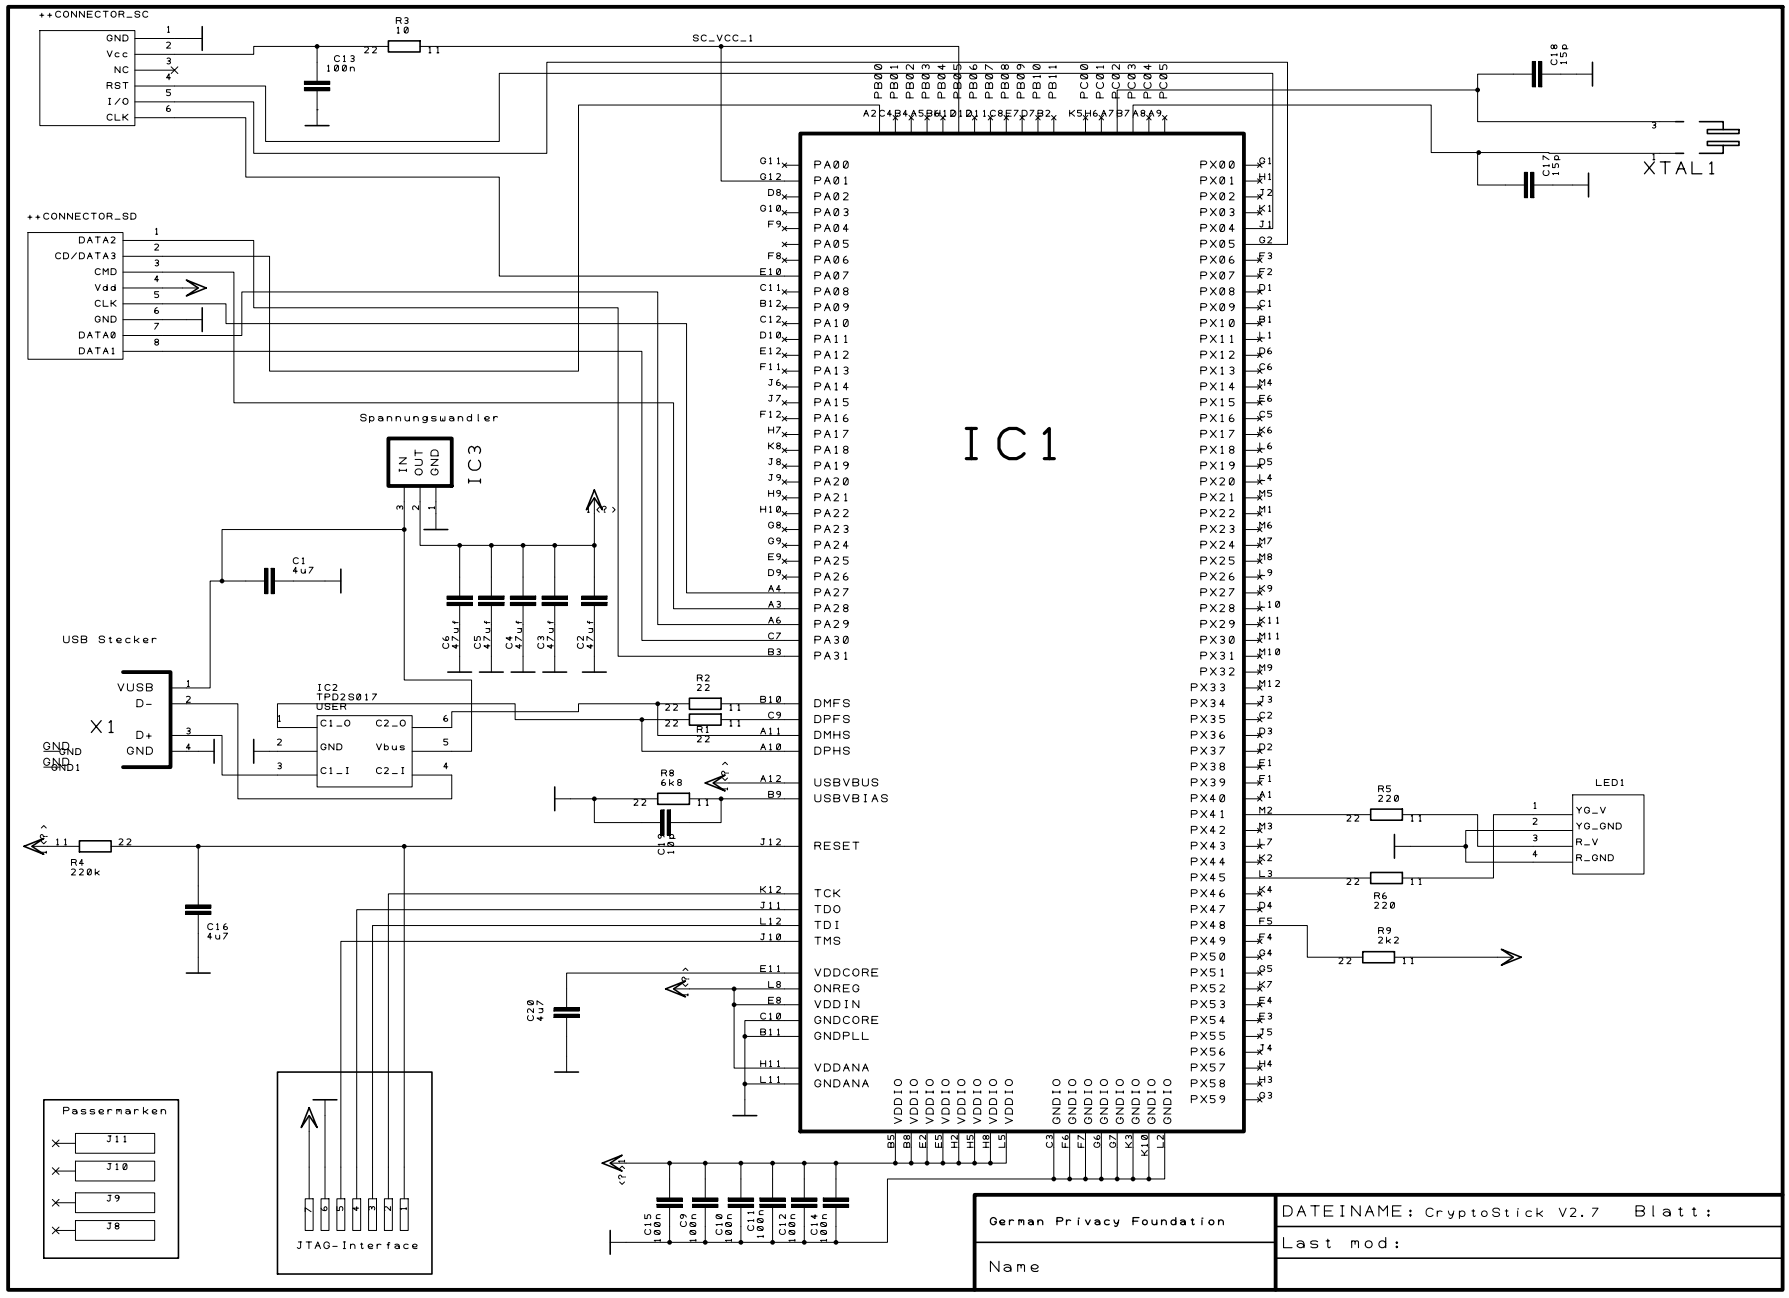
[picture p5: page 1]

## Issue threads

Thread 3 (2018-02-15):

Use faster MCU

jans23, 2018-02-15:
Perhaps [this one](http://www.st.com/en/evaluation-tools/stm32h753i-eval.html).

szszszsz, 2018-02-15:
It would be great to choose such MCU that would allow to match maximum transfer speed of SD card reader.
If that it is possible, then SD reader and SD card themselves could be replaced for faster versions as well.

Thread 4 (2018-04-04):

Add button for various added functionality

szszszsz, 2018-04-04:
> All of this would be perfect if the device gets a button to "re-insert" the stick. The same button could be used to send keystrokes (as yubikey does) so you could get OTP without the need of an app.
Source: https://github.com/Nitrokey/nitrokey-app/issues/337#issuecomment-377646808

szszszsz, 2018-04-04:
Related: https://github.com/Nitrokey/nitrokey-pro-hardware/issues/2

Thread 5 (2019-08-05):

Use not hacked MCU

no111u3, 2019-08-05:
The current STM32 mcu's have easy to reproduce hack metodology - https://www.aisec.fraunhofer.de/en/FirmwareProtection.html.

I think stm32 mcu's are dangerous for key storage.

jans23, 2019-08-05:
Nitrokey Storage doesn't contain a STM32. Instead it contains a certified smart card to store cryptographic keys.

szszszsz, 2019-08-06:
@no111u3  to add:
- in the paper, STM32F0 was investigated, which is a different chip than we use in our products;
- possibility to use the same techniques over other STM32 families are mentioned, but not confirmed by the researchers;
- by design we have assumed flash can be read by adversary - user data are encrypted at rest (besides OTP data, about which we warn users in the Nitrokey App);
- one would argue, that using UV and chemicals to decap the MCU is easy to do (for RDP level decrease; which still might result in losing secret data anyway), while installing malware on the PC and fooling user would be much more feasible;
- finally, by the rule, the device you have lost physical access to is not your device anymore - it can have replaced MCU, modified firmware, have additional MCU in the middle for recording or modifying communication, or even sending data wirelessly to other device/PC.

Additionally, Pro and Storage products contain smart cards, which keep the actual secrets - OpenPGP keys, user custom data, and internal data encryption key.

Closed 2019-08-05.

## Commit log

2014-12-22 Initial commit, migrating
    [BOM.xlsx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]
2015-01-06 fixed caps and resistor components length (manually)
2015-01-07 TLV fixes + slot resize
2015-09-08 Move V1.0 to own directory
    [BOM.xlsx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]
2015-09-08 V1.1 JTAG interface removed
    [BOM.xlsx, NitrokeyV11.sch]
2015-10-05 Nitrokey Storage V1.2 - Replaced 1206 components to 0805, 0603 - Adapted board outline to new enclosure
    [BOM.xlsx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]
2015-11-23 Nitroykey Storage Hardware V1.3 - Adapted board outline to new enclosure - 3 components placed away from board outline
    [BOM.xlsx, NitrokeyV13 (Bill Of Materials).csv, NitrokeyV13 (Component Positions CSV).csv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]
2015-11-27 Weitere Datei für die Fertigung
